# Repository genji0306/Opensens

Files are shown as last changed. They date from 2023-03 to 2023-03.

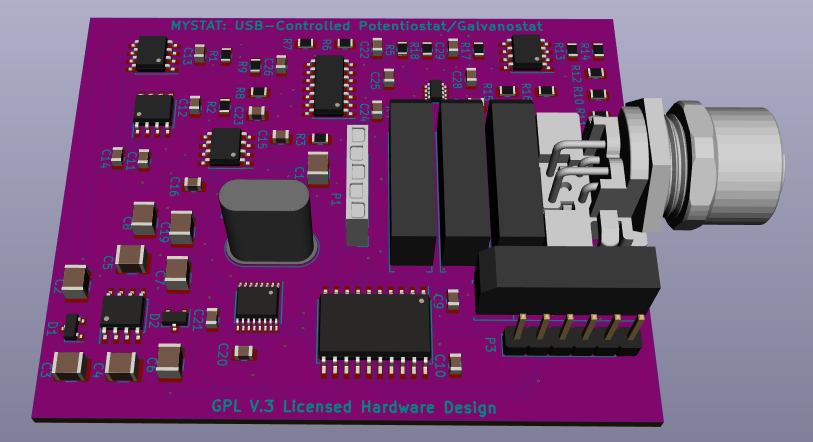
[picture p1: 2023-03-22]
OEPS V2b Zenodo Based/pcb_3dview.png

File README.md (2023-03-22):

# Opensens
Opensource Potentiostat
Sau khi chia sẻ điện cực in SPE, Lab em đã nhận được sự nhiều sự quan tâm và liên hệ. Nhóm em nhận thấy là hiện tại việc nghiên cứu về Electrochemistry và Biosensor của các nhóm nghiên cứ ở trong VN còn nhiều khó khăn đặt biệt là về vấn đề thiết bị. Chính vì vậy, lab em quyết định chia sẻ phần nghiên cứu về thiết bị đo điện hoá Potentiostat/Galvanostat cho mọi người, hy vọng có thể giảm bớt khó khăn khi nghiên cứu trong nước Potentiostat/Galvanostat do nhóm DYNLAB- PGS. Thuỷ, thuộc Bộ Môn Điện Hoá, Đại Học Bách Khoa Hà Nội và nhóm PGS. Nguyên, ĐH KHTN HCM - phát triển – tên mã project là OEPS – tên chính thức là Opensens, được phát triển từ cuối năm 2017 với mục tiêu là tạo ra thiết bị đo điện hoá nhỏ gọn tin cậy độ phân giải cao, giá thành hợp lý để triển khai giám sát trên diện rộng. Version đầu tiên dựa trên phiên bản của TS. Dobbelaere và bản sau này của Irving (NCS của Dobbelaere). Phiên bản OEPS V1 dựa trên hardware với một số thay đổi về linh kiện, firmware và phần mềm. Sau 5 năm nghiên cứu, hiện nhóm đã phát triển nhiều Version khác nhau phục vụ cho nghiên cứu về Nguồn điện (Pin), Cảm Biến và giám sát môi trường. 
Trong link chia sẻ là bản OEPS V1/V2, MFO V1 và cả Software gốc/ Software của lab: 
- OEPS V1: Gồm một số tính năng: LSV, CV, CP, CA, Phóng nạp Pin - dải điện áp +-8V 30mA - hiệu chỉnh lỗi và tương thích software bản mới. (DAC 22 bits - độ phân giải 4pA) 
- OEPS V2: Dải điện áp +-12V 250mA - modify chống nhiễu, thay đổi linh kiện giá hợp lý hơn và chỉnh sửa lại Software.
- MFO V1: Phiên bản rút gọn đo 1 phép đo set up sẵn dùng cho y sinh/ môi trường. Có khả năng đo được hầu hết các phép đo LSV,CV,CP,CA, DPV, NPV, EIS(<34khz) (độ phân giải thấp – 12 bits) 
Các phiên bản trên đã được chạy thử nghiệm ít nhất 2 năm và nhiều nhất là từ khi dự án được tiến hành, đã so sánh với thiết bị thương mại như Autolab, Biologic và Palmsens. Các phiên bản khác của lab được tích hơn thêm Pulse technique và EIS sẽ sớm được opensource trong thời gian tiếp theo. Nếu muốn trải nghiệm thiết bị, xin mời mọi người qua DHBK HN ở Hà Nội gặp và Trường DH KHTN HCM ở HCM gặp PGS. Nguyên .

Chi phí linh kiện của thiết bị dao động từ $120-150, tuy nhiên thực tế tuỳ số lượng, đơn vị gia công và thuế nhập khẩu, chi phí sx rơi vào tầm 5-8tr/ thiết bị. Mọi người chỉ cần gửi link và liên hệ bên điện điện tử là được. Cũng chia sẻ luôn, tầm giữa tháng 4 tại bên lab sẽ đặt thêm linh kiện và gia công thiết bị (phiên bản mới) nhưng có chung nhiều linh kiện phiên bản cũ. Vì vậy nếu cần thì bên em có thể đặt giúp mọi người. Chi tiết xin liên hệ sdt: 033. 616.4867 

Ps: do phải tách repo Git để opensource nên dữ liệu sẽ được upload dần từ giờ tới cuối tuần

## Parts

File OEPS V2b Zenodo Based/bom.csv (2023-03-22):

Component | Description | Part | References | Value | Footprint | Quantity Per PCB | Datasheet | Part Number | Manufacturer
1 | Unpolarized capacitor | C_Small | C9 C10 C11 C12 C13 C14 C15 C16 C22 C23 C25 C27 C28 | 0.1 µF | C_0805_2012Metric | 13 | https://api.kemet.com/component-edge/download/datasheet/C0805C104J5RALTU.pdf | C0805C104J5RAL7800 C0805C104J3RACTU | KEMET
2 | Unpolarized capacitor | C_Small | C21 | 10 nF | C_0805_2012Metric | 1 | https://api.kemet.com/component-edge/download/datasheet/C0805C103J5GACTU.pdf | C0805C103J5GACTU | KEMET
3 | Unpolarized capacitor | C_Small | C1 C2 C3 C4 C5 C6 C7 C8 C19 | 10 µF | C_1210_3225Metric | 9 | http://search.murata.co.jp/Ceramy/image/img/A01X/G101/ENG/GRM32DR71E106KA12-01.pdf | GRM32DR71E106KA12L | Murata Electronics North America
4 | Unpolarized capacitor | C_Small | C17 C18 C26 C29 | 12 pF | C_0805_2012Metric | 4 | http://www.yageo.com/documents/recent/UPY-GP_NP0_16V-to-50V_16.pdf | CC0805FRNPO9BN120 | Yageo
5 | Unpolarized capacitor | C_Small | C20 | 3.3 nF | C_0805_2012Metric | 1 | https://www.murata.com/~/media/webrenewal/support/library/catalog/products/capacitor/mlcc/c02e.ashx | GRM2165C1H332FA01J | Murata Electronics North America
6 | Unpolarized capacitor | C_Small | C24 | 4700 pF | C_0805_2012Metric | 1 | https://api.kemet.com/component-edge/download/datasheet/C0805C472K5RACTU.pdf | C0805C472K5RACTU | KEMET
7 | Dual schottky diode | D_Schottky_x2_Serial_AKC | D1 D2 | BAT721S | SOT-23 | 2 | https://assets.nexperia.com/documents/data-sheet/1PS76SB21_BAT721_SER.pdf | BAT721S,215 | Nexperia USA Inc.
8 |  | 9007-05-01 | K1 K2 K3 K4 | 9007-05-01 | RELAY-9007 | 4 | https://cotorelay.com/wp-content/uploads/2014/09/9007_series_reed_relay_datasheet.pdf | 9007-05-01 | Coto Technology
9 | Generic connector, single row, 01x05, script generated (kicad-library-utils/schlib/autogen/connector/) | Conn_01x05 | P2 | CELL | T4145035041-001 | 1 | http://www.te.com/commerce/DocumentDelivery/DDEController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 | T4145035041-001 | TE Connectivity AMP Connectors
10 | Generic connector, single row, 01x06, script generated (kicad-library-utils/schlib/autogen/connector/) | Conn_01x06 | P3 | ICSP | PinHeader_1x06_P2.54mm_Vertical | 1 | https://media.digikey.com/PDF/Data%20Sheets/Sullins%20PDFs/xRxCzzzSxxN-RC_ST_11635-B.pdf | PRPC006SAAN-RC | Sullins Connector Solutions
11 |  | USB_Header | P1 | USB Terminal | PinHeader_1x05_P2.54mm_Vertical | 1 | http://www.te.com/commerce/DocumentDelivery/DDEController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 | 215297-5 | TE Connectivity AMP Connectors
12 | Resistor, small symbol | R_Small | R12 | 100k* | R_0805_2012Metric | 1 | https://industrial.panasonic.com/cdbs/www-data/pdf/RDM0000/AOA0000C307.pdf | ERA-6AEB104V | Panasonic Electronic Components
13 | Resistor, small symbol | R_Small | R10 | 10R* | R_0805_2012Metric | 1 | http://www.te.com/commerce/DocumentDelivery/DDEController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 | CPF0805B10RE | TE Connectivity Passive Product
14 | Resistor, small symbol | R_Small | R2 R5 | 10k | R_0805_2012Metric | 2 | http://www.yageo.com/documents/recent/PYu-RC_Group_51_RoHS_L_9.pdf | RC0805FR-0710KL | Yageo
15 | Resistor, small symbol | R_Small | R13 | 18k* | R_0805_2012Metric | 1 | https://industrial.panasonic.com/cdbs/www-data/pdf/RDM0000/AOA0000C307.pdf | ERA-6AEB183V | Panasonic Electronic Components
16 | Resistor, small symbol | R_Small | R1 R3 | 1k | R_0805_2012Metric | 2 | http://www.yageo.com/documents/recent/PYu-RC_Group_51_RoHS_L_9.pdf | RC0805FR-071KL | Yageo
17 | Resistor, small symbol | R_Small | R11 | 1k* | R_0805_2012Metric | 1 | https://industrial.panasonic.com/cdbs/www-data/pdf/RDM0000/AOA0000C307.pdf | ERA-6AEB102V | Panasonic Electronic Components
18 | Resistor, small symbol | R_Small | R6 R8 | 240k* | R_0805_2012Metric | 2 | http://www.susumu.co.jp/common/pdf/n_catalog_partition01_en.pdf | RG2012N-244-W-T1 | Susumu
19 | Resistor, small symbol | R_Small | R4 | 27R | R_0805_2012Metric | 1 | http://www.yageo.com/documents/recent/PYu-RC_Group_51_RoHS_L_9.pdf | RC0805FR-0727RL | Yageo
20 | Resistor, small symbol | R_Small | R14 | 2k* | R_0805_2012Metric | 1 | https://industrial.panasonic.com/cdbs/www-data/pdf/RDM0000/AOA0000C307.pdf | ERA-6AEB202V | Panasonic Electronic Components
21 | Resistor, small symbol | R_Small | R7 R9 R15 R16 R17 R18 | 75k* | R_0805_2012Metric | 6 | https://industrial.panasonic.com/cdbs/www-data/pdf/RDM0000/AOA0000C307.pdf | ERA-6ARW753V | Panasonic Electronic Components
22 |  | ADR421 | U3 | ADR421 | SOIC-8_3.9x4.9mm_P1.27mm | 1 | http://www.analog.com/media/en/technical-documentation/data-sheets/ADR420_421_423_425.pdf | ADR421ARZ | Analog Devices Inc.
23 |  | DAC1220 | U6 | DAC1220 | SSOP-16_3.9x4.9mm_P0.635mm | 1 | http://www.ti.com/lit/ds/symlink/dac1220.pdf | DAC1220E | Texas Instruments
24 |  | DG449 | U8 | DG449 | sot23-8 | 1 | http://www.vishay.com/docs/73897/dg449.pdf | DG449DS-T1-E3 | Vishay Siliconix
25 |  | LM2662 | U1 | LM2662 | SOIC-8_3.9x4.9mm_P1.27mm | 1 | http://www.ti.com/lit/ds/symlink/lm2662.pdf | LM2662M/NOPB | Texas Instruments
26 |  | MCP3550 | U4 U5 | MCP3553 | SOIC-8_3.9x4.9mm_P1.27mm | 2 | http://www.microchip.com/mymicrochip/filehandler.aspx?ddocname=en024716 | MCP3553-E/SN | Microchip Technology
27 |  | OPA2192 | U9 | OPA2192 | SOIC-8_3.9x4.9mm_P1.27mm | 1 | http://www.ti.com/lit/ds/symlink/opa192.pdf | OPA2192IDR | Texas Instruments
28 |  | OPA4192 | U7 | OPA4192 | SOIC-14_3.9x8.7mm_P1.27mm | 1 | http://www.ti.com/lit/ds/symlink/opa4192.pdf | OPA4192IDR | Texas Instruments
29 |  | PIC16F1459 | U2 | PIC16F1459 | SOIC-20W_7.5x12.8mm_P1.27mm | 1 | http://www.microchip.com/mymicrochip/filehandler.aspx?ddocname=en558409 | PIC16F1459-I/SO | Microchip Technology
30 | Two pin crystal, small symbol | Crystal_Small | X1 | 2.5 MHz | Crystal_HC49-U_Vertical | 1 | http://www.ecsxtal.com/store/pdf/hc49ux.pdf | ECS-25-S-1X | ECS Inc.
Component Groups: | 30
Component Count: | 66
Fitted Components: | 66
Number of PCBs: | 1
Total components: | 66
Schematic Version: | 1
Schematic Date: | 2018-07-27
BoM Date: | Fri 27 Jul 2018 05:08:33 PM EDT
Schematic Source: | /home/matt/mystat-master/kicad3/mystat.sch
KiCad Version: | Eeschema 5.0.0+dfsg1-1

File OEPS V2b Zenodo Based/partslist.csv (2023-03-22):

Index | Quantity | Part Number | Description | Customer Reference | Available Quantity | Backorder Quantity | Unit Price USD | Extended Price USD
1 | 1 | 399-7992-1-ND | CAP CER 10000PF 50V C0G/NP0 0805 |  | 1 | 0 | 0.69 | 0.69
2 | 4 | 311-4162-1-ND | CAP CER 12PF 50V NPO 0805 |  | 4 | 0 | 0.3 | 1.2
3 | 1 | 490-8287-1-ND | CAP CER 3300PF 50V C0G/NP0 0805 |  | 1 | 0 | 0.49 | 0.49
4 | 1 | 399-1155-1-ND | CAP CER 4700PF 50V X7R 0805 |  | 1 | 0 | 0.1 | 0.1
5 | 2 | 1727-3574-1-ND | DIODE ARRAY SCHOTTKY 40V SOT23 |  | 2 | 0 | 0.45 | 0.9
6 | 4 | 306-1063-ND | RELAY REED SPST 500MA 5V |  | 4 | 0 | 1.43 | 5.72
7 | 1 | A126527-ND | CONN RCPT FMALE 4POS GOLD SOLDER |  | 1 | 0 | 10.44 | 10.44
8 | 1 | S1011EC-06-ND | CONN HEADER .100" SNGL STR 6POS |  | 1 | 0 | 0.23 | 0.23
9 | 1 | A113138-ND | CONN RCPT HV-100 SRS VERT 5POS |  | 1 | 0 | 1.1 | 1.1
10 | 1 | P100KDACT-ND | RES SMD 100K OHM 0.1% 1/8W 0805 |  | 1 | 0 | 0.41 | 0.41
11 | 1 | A119971CT-ND | RES SMD 10 OHM 0.1% 1/10W 0805 |  | 1 | 0 | 0.53 | 0.53
12 | 2 | 311-10.0KCRCT-ND | RES SMD 10K OHM 1% 1/8W 0805 |  | 2 | 0 | 0.1 | 0.2
13 | 1 | P18KDACT-ND | RES SMD 18K OHM 0.1% 1/8W 0805 |  | 1 | 0 | 0.41 | 0.41
14 | 2 | 311-1.00KCRCT-ND | RES SMD 1K OHM 1% 1/8W 0805 |  | 2 | 0 | 0.1 | 0.2
15 | 1 | P1.0KDACT-ND | RES SMD 1K OHM 0.1% 1/8W 0805 |  | 1 | 0 | 0.41 | 0.41
16 | 2 | RG20N240KWCT-ND | RES SMD 240K OHM 0.05% 1/8W 0805 |  | 2 | 0 | 0.93 | 1.86
17 | 1 | 311-27.0CRCT-ND | RES SMD 27 OHM 1% 1/8W 0805 |  | 1 | 0 | 0.1 | 0.1
18 | 1 | P2.0KDACT-ND | RES SMD 2K OHM 0.1% 1/8W 0805 |  | 1 | 0 | 0.41 | 0.41
19 | 6 | P75KBSCT-ND | RES SMD 75K OHM 0.05% 1/8W 0805 |  | 6 | 0 | 0.82 | 4.92
20 | 1 | ADR421ARZ-ND | IC VREF SERIES 2.5V 8SOIC |  | 1 | 0 | 6.62 | 6.62
21 | 1 | DAC1220E-ND | IC 20-BIT MONOLITHIC D/A 16SSOP |  | 1 | 0 | 19.8 | 19.8
22 | 1 | DG449DS-T1-E3CT-ND | IC SWITCH SINGLE SPDT SOT23-8 |  | 1 | 0 | 1.5 | 1.5
23 | 1 | LM2662M/NOPB-ND | IC REG SWTCHD CAP INV 0.2A 8SOIC |  | 1 | 0 | 2.57 | 2.57
24 | 2 | MCP3553-E/SN-ND | IC ADC 22BIT 2.7V 1CH SPI 8SOIC |  | 2 | 0 | 4.1 | 8.2
25 | 1 | 296-42106-1-ND | IC OP AMP RRIO E-TRIM 8SOIC |  | 1 | 0 | 4.2 | 4.2
26 | 1 | 296-43159-1-ND | IC OPAMP RRI/O 14SOIC |  | 1 | 0 | 6.61 | 6.61
27 | 1 | PIC16F1459-I/SO-ND | IC MCU 8BIT 14KB FLASH 20SOIC |  | 1 | 0 | 1.82 | 1.82
28 | 1 | X1003-ND | CRYSTAL 2.5000MHZ SERIES T/H |  | 1 | 0 | 1.13 | 1.13
29 | 9 | 490-1867-1-ND | CAP CER 10UF 25V X7R 1210 |  | 9 | 0 | 0.83 | 7.47
30 | 1 | HM3149-ND | BOX ALUM BLACK 3.48"L X 2.44"W |  | 1 | 0 | 26.95 | 26.95
31 | 1 | 708-1230-ND | CABLE IP68 MINI B TO A USB 3M |  | 1 | 0 | 19.77 | 19.77
32 | 1 | 708-1236-ND | CABLE IP68 B MINI USB-5WAY HEADE |  | 1 | 0 | 10.58 | 10.58
33 | 1 | 277-12857-ND | SENSOR/ACTUATOR CABLE 4POS |  | 1 | 0 | 14.96 | 14.96

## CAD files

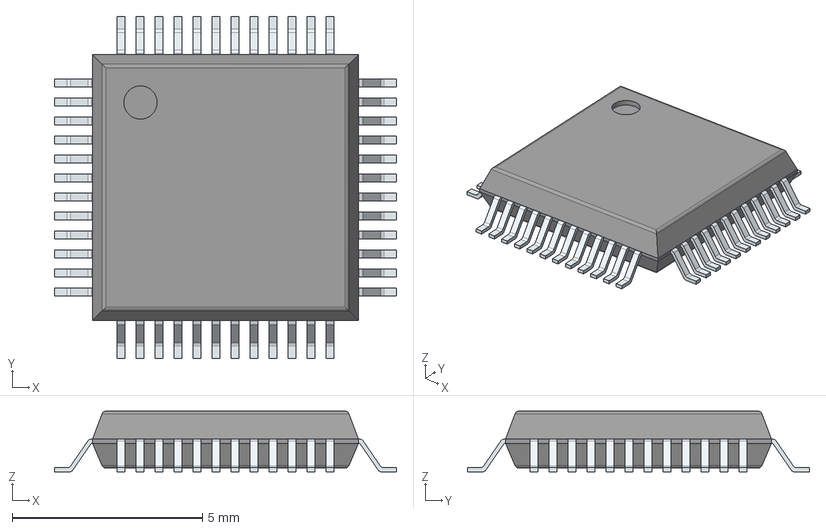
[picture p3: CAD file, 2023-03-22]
OEPS V2 STM/STM32F072C8T6-pcb-part-libraries/STM32F072C8T6.stp
9.00 x 9.00 x 1.60 mm
PinsArrayLR
PinsArrayTB

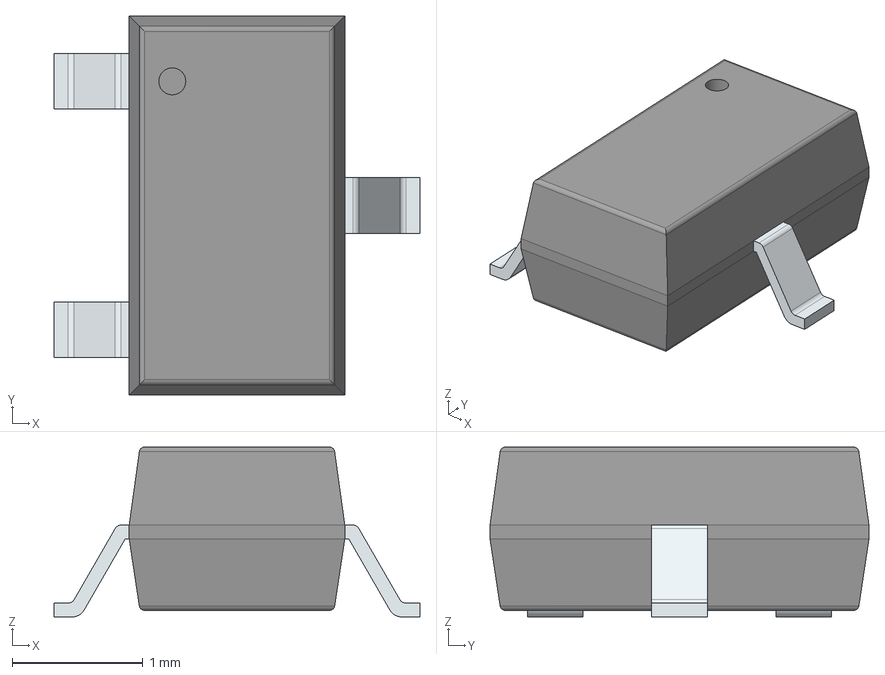
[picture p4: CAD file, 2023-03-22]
OEPS V2 STM/XC6206P332MR-G-pcb-part-libraries/XC6206P332MR-G.stp
2.80 x 2.90 x 1.30 mm
PinsArrayL
FilletPinR

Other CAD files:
OEPS V2 STM/STM32F072C8T6-pcb-part-libraries/STM32F072C8T6.stl
OEPS V2 STM/XC6206P332MR-G-pcb-part-libraries/XC6206P332MR-G.stl

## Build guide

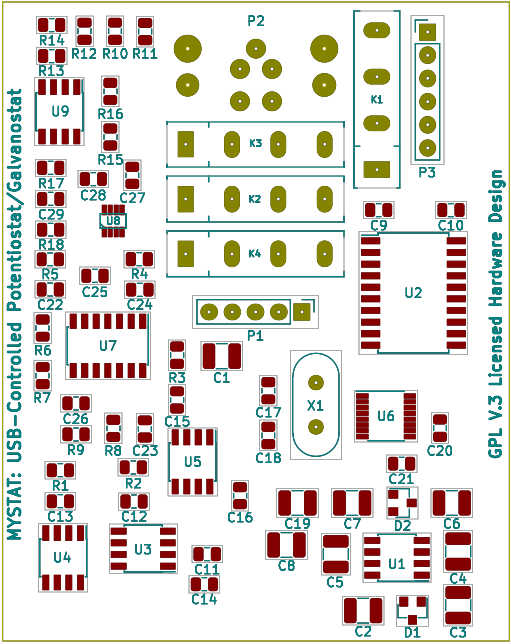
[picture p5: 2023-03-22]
OEPS V2b Zenodo Based/pcb_fabrication_diagram.png

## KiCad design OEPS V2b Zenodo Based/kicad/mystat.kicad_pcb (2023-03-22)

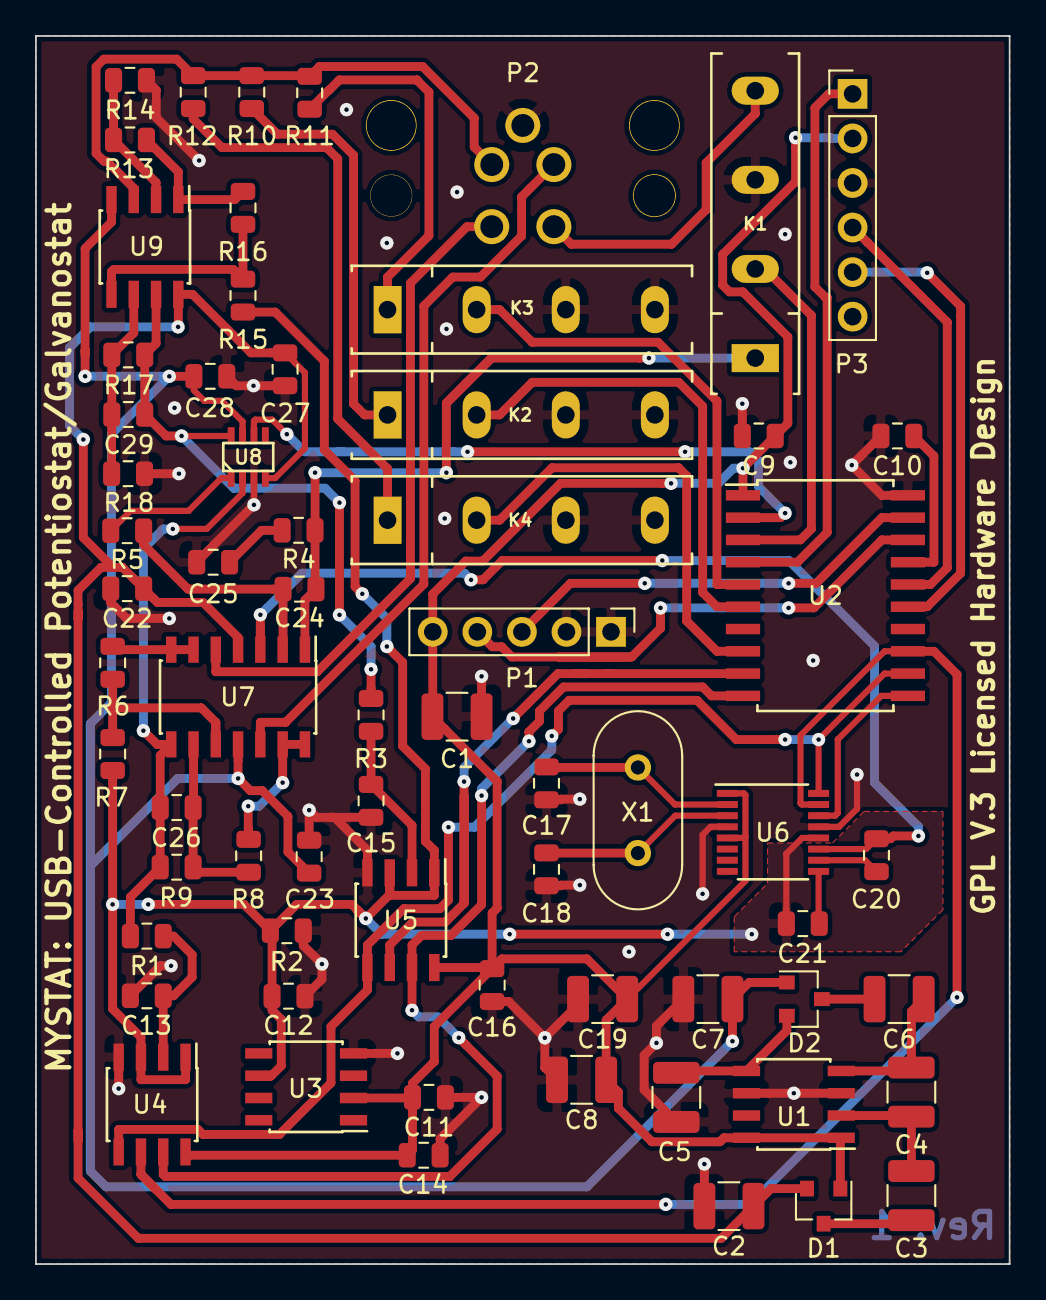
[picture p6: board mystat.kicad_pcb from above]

Board: 2 copper layers, 55.5 x 70.0 mm, 66 parts (0 on the bottom side), 54 nets.

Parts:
C1, C2, C3, C4, C5, C6, C7, C8, C19: 10 µF; C_1210_3225Metric
C9, C10, C11, C12, C13, C14, C15, C16, C22, C23, C25, C27, C28: 0.1 µF; C_0805_2012Metric
C17, C18, C26, C29: 12 pF; C_0805_2012Metric
C20: 3.3 nF; C_0805_2012Metric
C21: 10 nF; C_0805_2012Metric
C24: 4700 pF; C_0805_2012Metric
D1, D2: BAT721S; SOT-23
K1, K2, K3, K4: 9007-05-01; RELAY-9007
P1: USB Terminal; PinHeader_1x05_P2.54mm_Vertical
P2: CELL; T4145035041-001
P3: ICSP; PinHeader_1x06_P2.54mm_Vertical
R1, R3: 1k; R_0805_2012Metric
R2, R5: 10k; R_0805_2012Metric
R4: 27R; R_0805_2012Metric
R6, R8: 240k*; R_0805_2012Metric
R7, R9, R15, R16, R17, R18: 75k*; R_0805_2012Metric
R10: 10R*; R_0805_2012Metric
R11: 1k*; R_0805_2012Metric
R12: 100k*; R_0805_2012Metric
R13: 18k*; R_0805_2012Metric
R14: 2k*; R_0805_2012Metric
U1: LM2662; SOIC-8_3.9x4.9mm_P1.27mm
U2: PIC16F1459; SOIC-20W_7.5x12.8mm_P1.27mm
U3: ADR421; SOIC-8_3.9x4.9mm_P1.27mm
U4, U5: MCP3553; SOIC-8_3.9x4.9mm_P1.27mm
U6: DAC1220; SSOP-16_3.9x4.9mm_P0.635mm
U7: OPA4192; SOIC-14_3.9x8.7mm_P1.27mm
U8: DG449; sot23-8
U9: OPA2192; SOIC-8_3.9x4.9mm_P1.27mm
X1: 2.5 MHz; Crystal_HC49-U_Vertical

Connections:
+5V: C1.1, C8.1, C9.1, C11.1, C14.1, C16.1, C19.1, D1.1, P1.1, P3.2, U1.1, U1.8, U2.1, U3.2, U4.8, U5.8, U6.1, U6.5
+9V: C2.1, C22.2, C27.2, D1.2, U7.4, U8.4, U9.8
-9V: C7.2, C23.1, C28.1, D2.1, U7.11, U8.7, U9.4
/CE: P2.3, R10.1, R11.1, R12.1, U9.3
/CELL_ON: K1.2, U2.3
/CS1: U2.11, U6.14
/CS2: U2.10, U4.7, U5.7
/ICSPCLK: P3.5, U2.15
/ICSPDAT: P3.4, U2.16
/I_MEAS: C29.2, R3.1, R17.2, U8.8, U9.7
/MCLR: P3.1, U2.4
/MODE_SW: U2.2, U8.6
/RANGE1: K2.2, U2.6
/RANGE2: K3.2, U2.5
/RANGE3: K4.2, U2.8
/RE: P2.4, U7.12
/SCK: U2.12, U4.5, U5.5, U6.16
/SDIO: U2.13, U4.6, U6.15
/SDIO2: U2.9, U5.6
/SE: P2.2, U7.5
/USB_D+: P1.3, U2.19
/USB_D-: P1.2, U2.18
/VREF: C12.1, C21.2, R2.1, R7.2, R15.1, U3.6, U4.1, U4.3, U5.1, U5.3, U6.12
/V_MEAS: C26.2, R1.1, R9.1, U7.8, U8.2
/WE: K1.4, P2.1
GND: C1.2, C2.2, C5.1, C7.1, C8.2, C9.2, C10.2, C11.2, C12.2, C13.2, C14.2, C15.2, C16.2, C17.2, C18.2, C19.2, C22.1, C23.2, C25.2, C27.1, C28.2, K1.3, K2.3, K2.4, K3.3, K3.4, K4.3, K4.4, P1.4, P1.5, P2.5, P3.3, R2.2, R14.2, R18.2, U1.3, U1.6, U2.20, U3.4, U4.4, U5.4, U6.4, U6.13, U8.3
unnamed: C3.1, D1.3
unnamed: C3.2, C4.1, U1.2
unnamed: C4.2, C6.1, U1.4
unnamed: C5.2, D2.2, U1.5
unnamed: C6.2, D2.3
unnamed: C10.1, U2.17
unnamed: C13.1, R1.2, U4.2
unnamed: C15.1, R3.2, U5.2
unnamed: C17.1, U6.2, X1.1
unnamed: C18.1, U6.3, X1.2
unnamed: C20.1, U6.10
unnamed: C20.2, U6.11, U7.3
unnamed: C21.1, U6.9
unnamed: C24.1, K1.1, R4.1, U7.1
unnamed: C24.2, R5.1, U7.2
unnamed: C25.1, R4.2
unnamed: C26.1, R8.1, R9.2, U7.9
unnamed: C29.1, R17.1, R18.1, U9.6
unnamed: K2.1, R10.2
unnamed: K3.1, R11.2
unnamed: K4.1, R12.2
unnamed: R5.2, U8.1
unnamed: R6.1, U7.6, U7.7
unnamed: R6.2, R7.1, U7.10
unnamed: R8.2, U7.13, U7.14
unnamed: R13.1, R14.1, U9.2
unnamed: R13.2, R16.1, U9.1
unnamed: R15.2, R16.2, U9.5

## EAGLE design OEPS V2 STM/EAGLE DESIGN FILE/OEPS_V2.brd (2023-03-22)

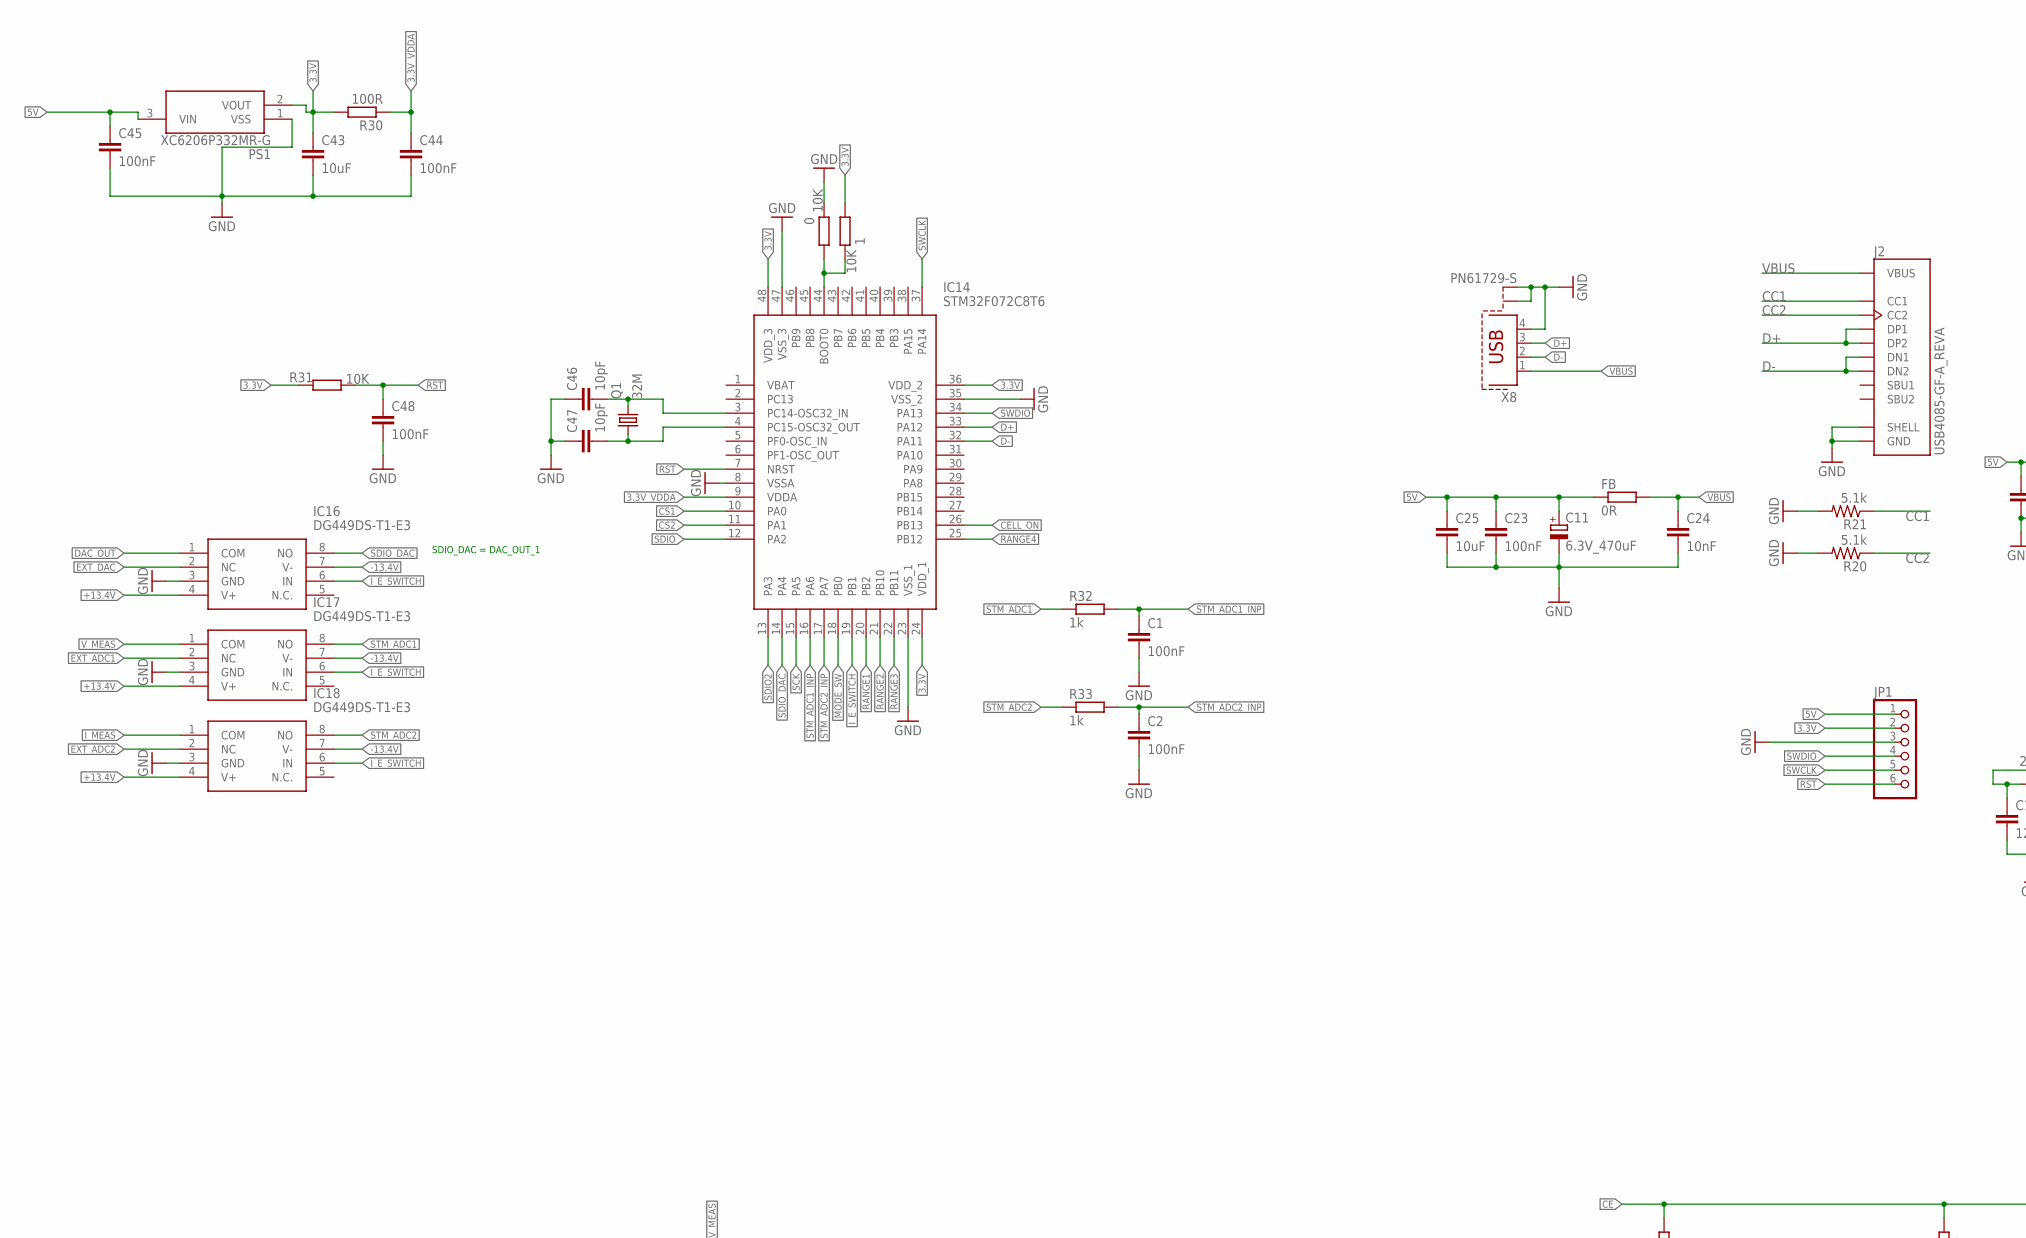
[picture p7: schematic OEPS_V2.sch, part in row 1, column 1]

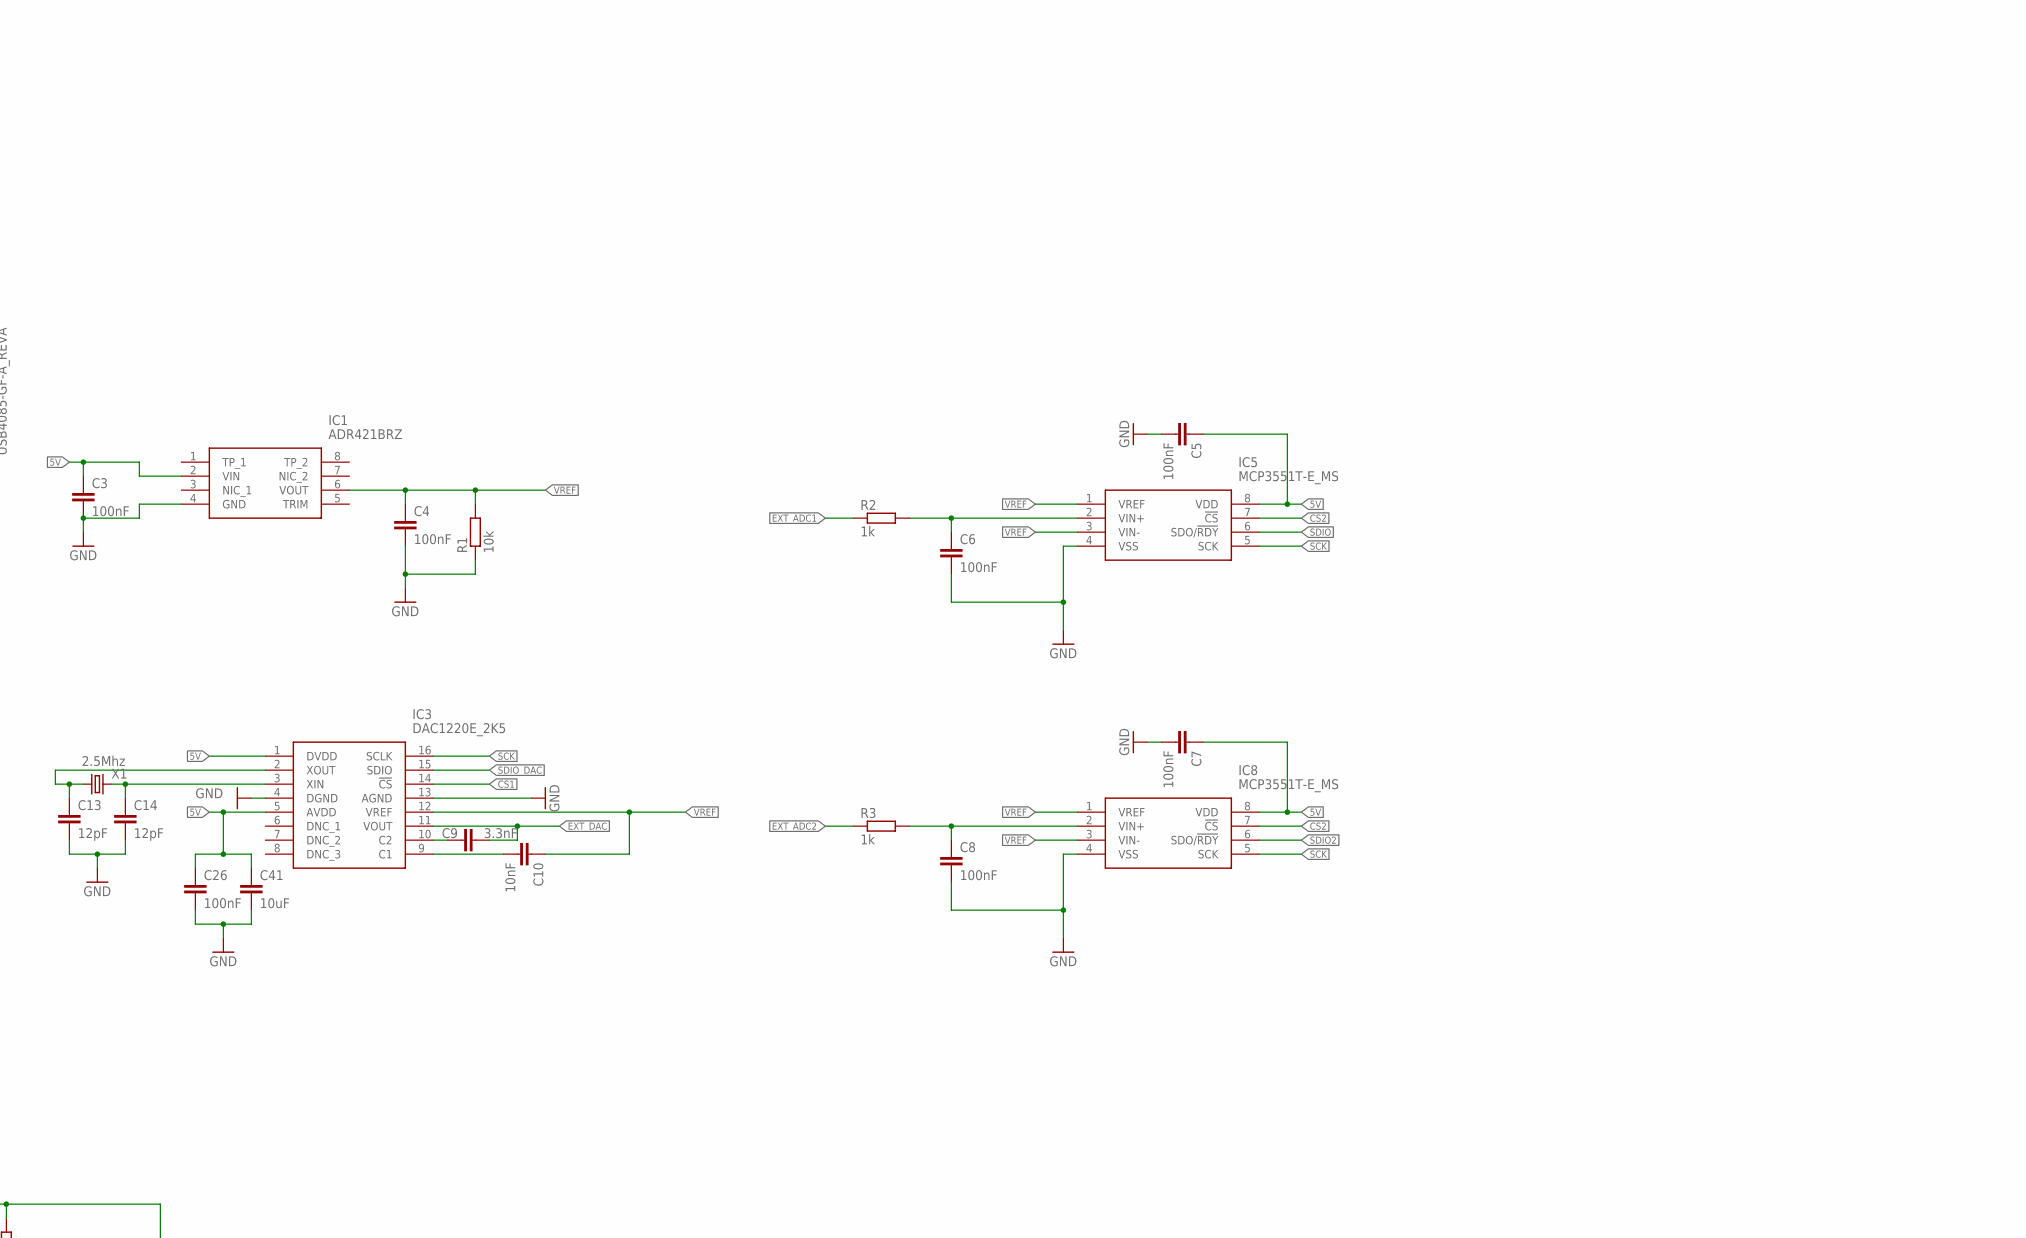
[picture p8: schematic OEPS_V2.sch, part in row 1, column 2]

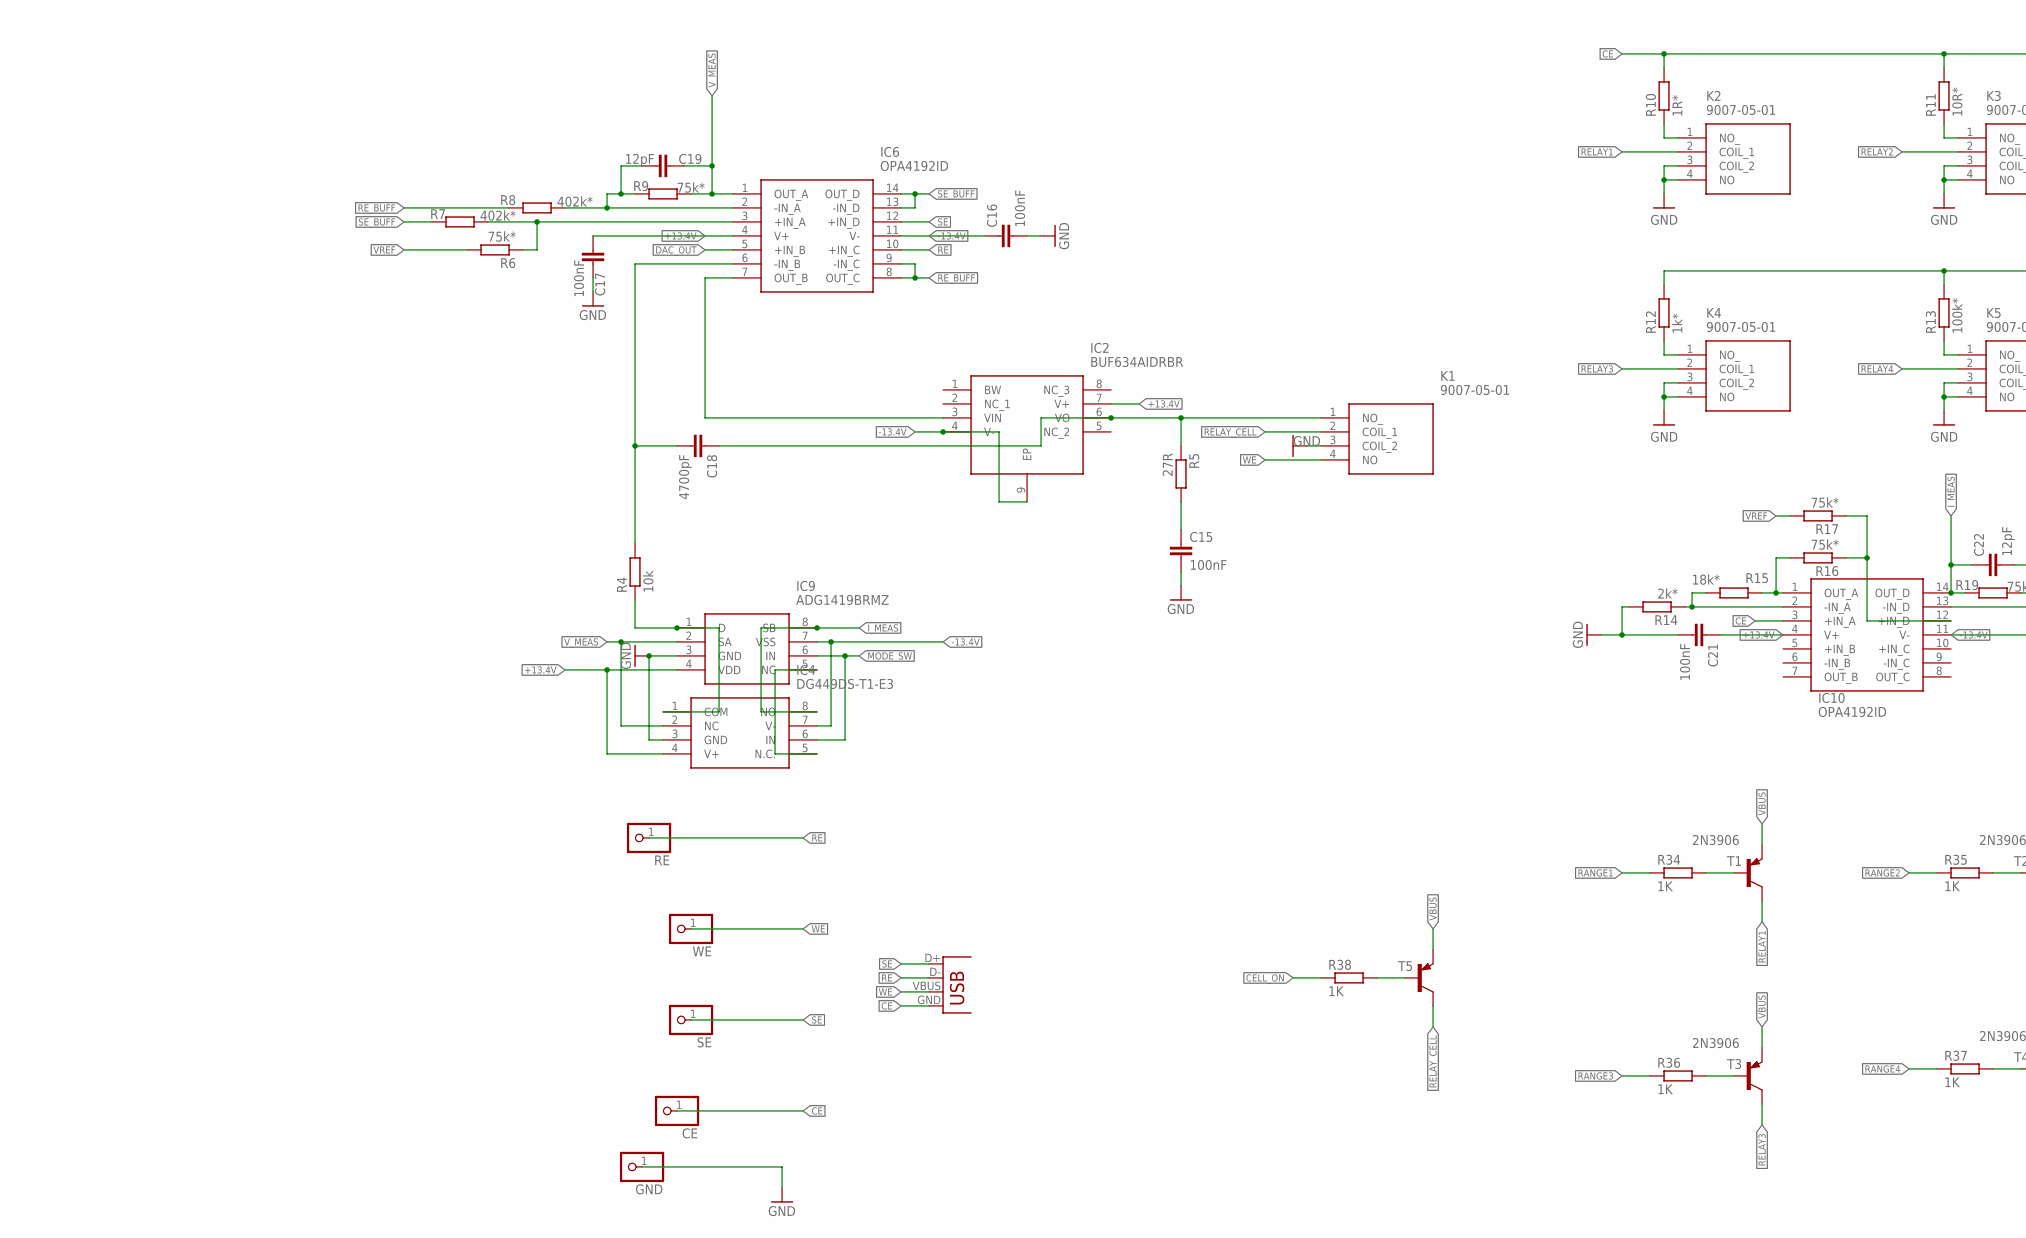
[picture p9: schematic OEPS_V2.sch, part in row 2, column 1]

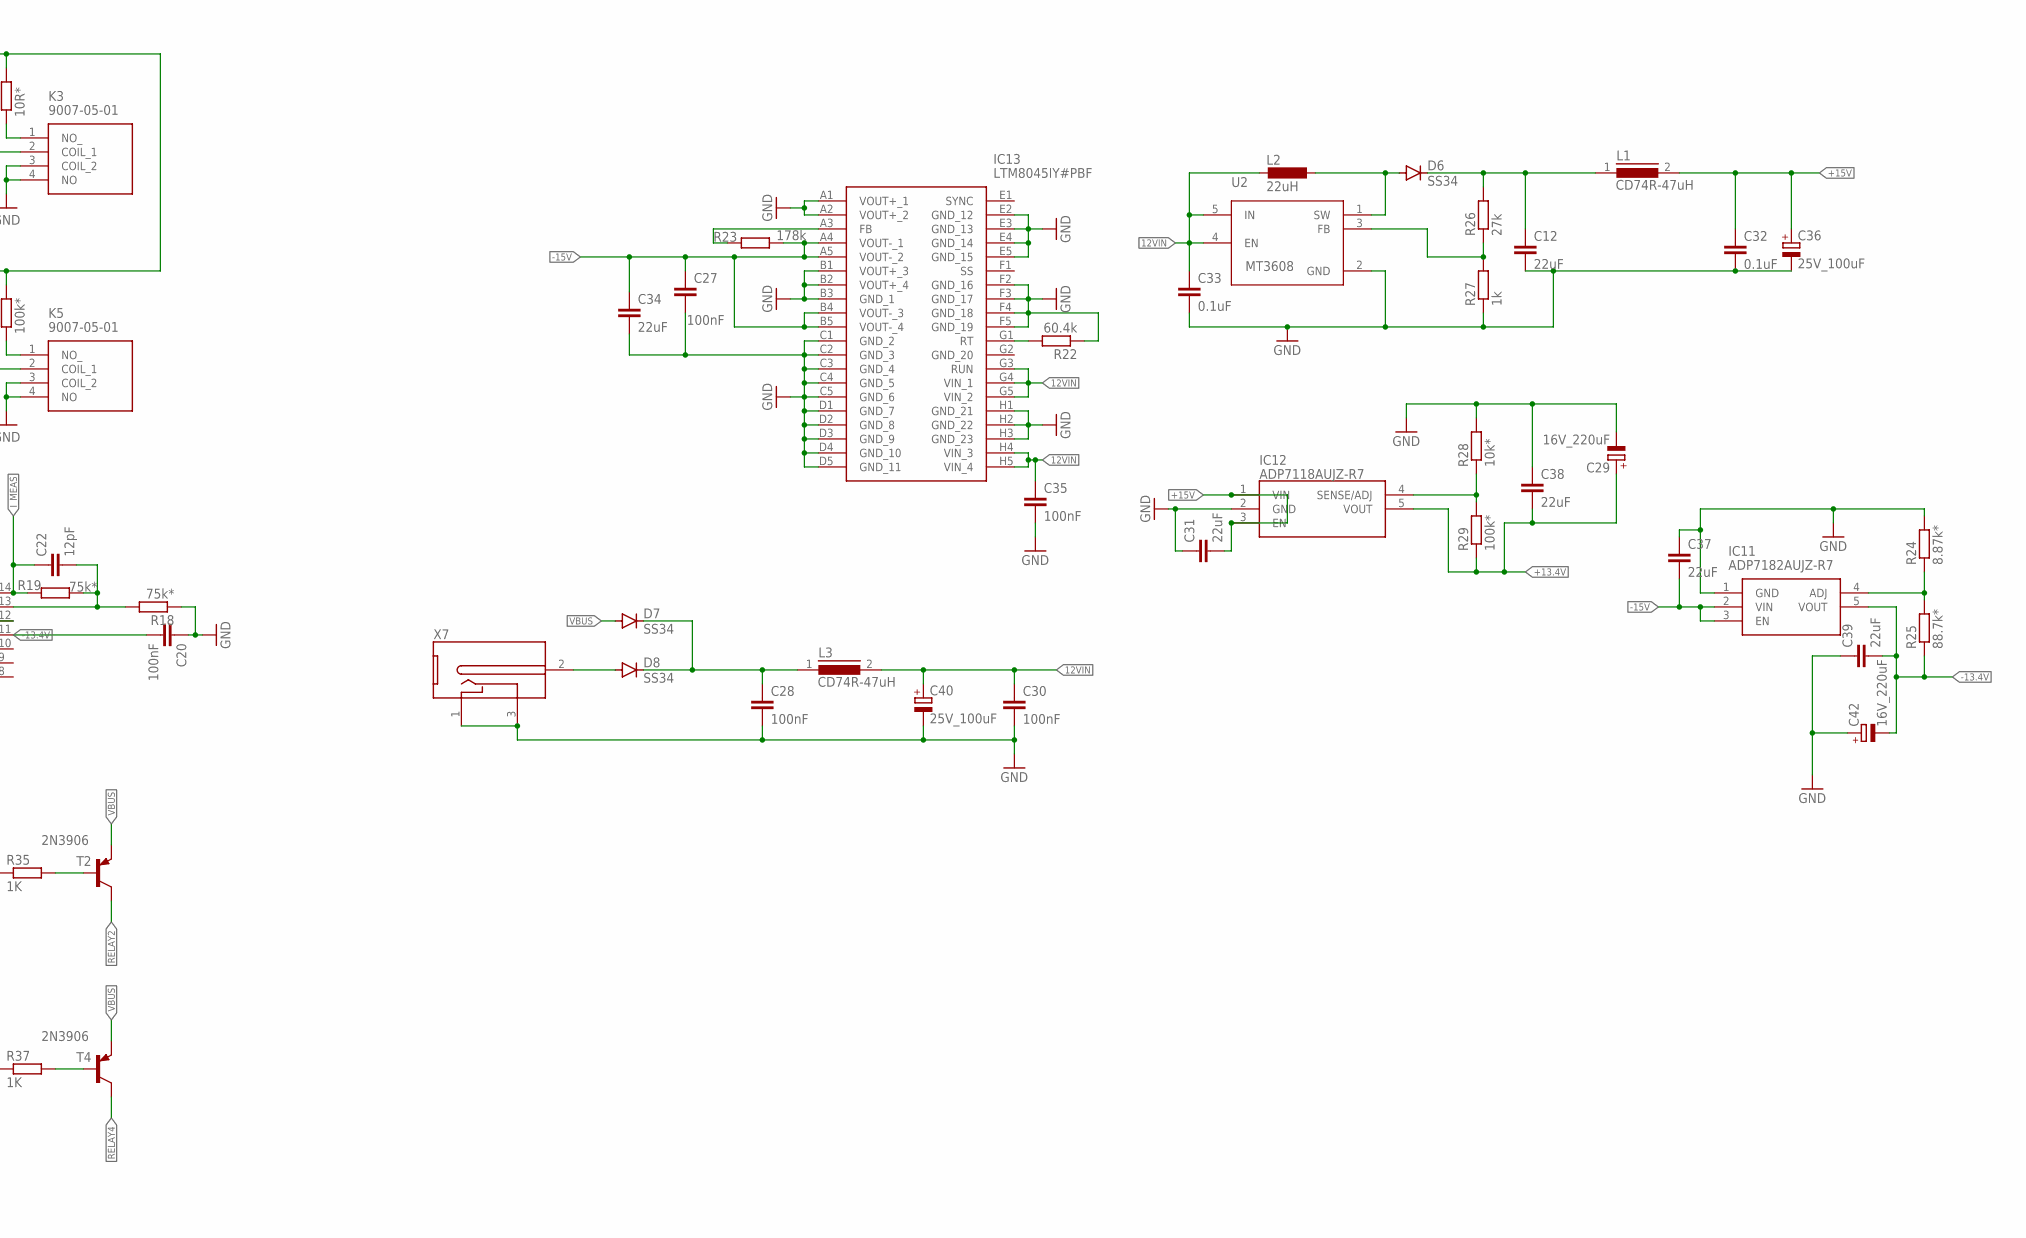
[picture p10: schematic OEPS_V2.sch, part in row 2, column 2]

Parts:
0, 1: 10K; R0603
C1, C2, C3, C4, C5, C6, C7, C8, C15, C16, C17, C20, C21, C23, C26, C44, C45, C48: 100nF; C0603
C9: 3.3nF; C0603
C10, C24: 10nF; C0603
C11: 6.3V_470uF; 153CLV-0605
C12, C31, C34, C37, C38, C39: 22uF; C1206
C13, C14, C19, C22: 12pF; C0603
C18: 4700pF; C0603
C25, C41, C43: 10uF; C0603
C27, C28, C30, C35: 100nF; C0805
C29, C42: 16V_220uF; 153CLV-0605
C32, C33: 0.1uF; C0805
C36, C40: 25V_100uF; 153CLV-0605
C46, C47: 10pF; C0603
CE: PINHD-1X1; 1X01
D6, D7, D8: SS34; DO-214AC
FB: 0R; R0805
GND: PINHD-1X1; 1X01
IC1: ADR421BRZ; SOIC127P600X175-8N
IC2: BUF634AIDRBR; SON65P300X300X100-9N
IC3: DAC1220E_2K5; SOP64P600X175-16N
IC4, IC16, IC17, IC18: DG449DS-T1-E3; SOP65P280X145-8N
IC5, IC8: MCP3551T-E_MS; SOP65P490X110-8N@1
IC6, IC10: OPA4192ID; SOIC127P600X175-14N
IC9: ADG1419BRMZ; SOP65P490X110-8N
IC11: ADP7182AUJZ-R7; SOT95P280X100-5N
IC12: ADP7118AUJZ-R7; SOT95P280X100-5N
IC13: LTM8045IY#PBF; BGA40C127P5X8_625X1125X512
IC14: STM32F072C8T6; QFP50P900X900X160-48N
J2: USB4085-GF-A_REVA; GCT_USB4085-GF-A_REVA
JP1: PINHD-1X6; 1X06
K1, K2, K3, K4, K5: 9007-05-01; 90070501
L1, L3: CD74R-47uH; DR74
L2: 22uH; PIS2816
PS1: XC6206P332MR-G; SOT95P280X130-3N
Q1: 32M; 3.2X2.5_KX-7
R1, R4: 10k; R0603
R2, R3, R27, R32, R33: 1k; R0603
R5: 27R; R0603
R6, R9, R16, R17, R18, R19: 75k*; R0603
R7, R8: 402k*; R0603
R10: 1R*; R0805
R11: 10R*; R0805
R12: 1k*; R0805
R13: 100k*; R0805
R14: 2k*; R0603
R15: 18k*; R0603
R20, R21: 5.1k; R0603
R22: 60.4k; R0603
R23: 178k; R0603
R24: 8.87k*; R0603
R25: 88.7k*; R0603
R26: 27k; R0603
R28: 10k*; R0603
R29: 100k*; R0603
R30: 100R; R0603
R31: 10K; R0603
R34, R35, R36, R37, R38: 1K; R0603
RE: PINHD-1X1; 1X01
SE: PINHD-1X1; 1X01
T1, T2, T3, T4: 2N3906; SOT23-BEC
T5: MMBT3906LT1-PNP-SOT23-BEC; SOT23-BEC
U2: MT3608; SOT95P280X145-6N
WE: PINHD-1X1; 1X01
X1: 2.5Mhz; HC49
X6: USB-A-H
X7: DC-2.1MM-5MM; DC-21MM
X8: PN61729-S

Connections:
3.3V: 1.2, C43.1, IC14.24 (VDD_1), IC14.36 (VDD_2), IC14.48 (VDD_3), JP1.2, PS1.2 (VOUT), R30.2, R31.2
3.3V_VDDA: C44.1, IC14.9 (VDDA), R30.1
5V: C3.1, C5.1, C7.1, C11.+, C23.1, C25.1, C26.1, C41.1, C45.1, FB.1, IC1.2 (VIN), IC3.1 (DVDD), IC3.5 (AVDD), IC5.8 (VDD), IC8.8 (VDD), JP1.1, PS1.3 (VIN)
12VIN: C30.1, C33.1, C35.1, C40.+, IC13.G3 (RUN), IC13.G4 (VIN_1), IC13.G5 (VIN_2), IC13.H4 (VIN_3), IC13.H5 (VIN_4), L2.2, L3.2, U2.4 (EN), U2.5 (IN)
+13.4V: C17.2, C21.1, C29.+, C38.2, IC2.7 (V+), IC4.4 (V+), IC6.4 (V+), IC9.4 (VDD), IC10.4 (V+), IC12.5 (VOUT), IC16.4 (V+), IC17.4 (V+), IC18.4 (V+), R29.1
+15V: C31.2, C32.1, C36.+, IC12.1 (VIN), IC12.3 (EN), L1.2
-13.4V: C16.1, C20.1, C39.2, C42.-, IC2.4 (V-), IC2.9 (EP), IC4.7 (V-), IC6.11 (V-), IC9.7 (VSS), IC10.11 (V-), IC11.5 (VOUT), IC16.7 (V-), IC17.7 (V-), IC18.7 (V-), R25.1
-15V: C27.1, C34.1, C37.2, IC11.2 (VIN), IC11.3 (EN), IC13.A4 (VOUT-_1), IC13.A5 (VOUT-_2), IC13.B4 (VOUT-_3), IC13.B5 (VOUT-_4), R23.2
CC1: J2.A5 (CC1), R21.1
CC2: J2.B5 (CC2), R20.1
CE: CE.1, IC10.3 (+IN_A), R10.2, R11.2, R12.2, R13.2, X6.GND
CELL_ON: IC14.26 (PB13), R38.1
CS1: IC3.14 (!CS), IC14.10 (PA0)
CS2: IC5.7 (!CS), IC8.7 (!CS), IC14.11 (PA1)
D+: IC14.33 (PA12), J2.A6 (DP1), J2.B6 (DP2), X8.3
D-: IC14.32 (PA11), J2.A7 (DN1), J2.B7 (DN2), X8.2
DAC_OUT: IC6.5 (+IN_B), IC16.1 (COM)
EXT_ADC1: IC17.2 (NC), R2.1
EXT_ADC2: IC18.2 (NC), R3.1
EXT_DAC: C9.1, IC3.11 (VOUT), IC16.2 (NC)
GND: 0.1, C1.2, C2.2, C3.2, C4.2, C5.2, C6.2, C7.2, C8.2, C11.-, C12.2, C13.2, C14.2, C15.2, C16.2, C17.1, C20.2, C21.2, C23.2, C24.2, C25.2, C26.2, C27.2, C28.2, C29.-, C30.2, C31.1, C32.2, C33.2, C34.2, C35.2, C36.-, C37.1, C38.1, C39.1, C40.-, C41.2, C42.+, C43.2, C44.2, C45.2, C46.1, C47.1, C48.2, GND.1, IC1.4 (GND), IC3.4 (DGND), IC3.13 (AGND), IC4.3 (GND), IC5.4 (VSS), IC8.4 (VSS), IC9.3 (GND), IC11.1 (GND), IC12.2 (GND), IC13.A1 (VOUT+_1), IC13.A2 (VOUT+_2), IC13.B1 (VOUT+_3), IC13.B2 (VOUT+_4), IC13.B3 (GND_1), IC13.C1 (GND_2), IC13.C2 (GND_3), IC13.C3 (GND_4), IC13.C4 (GND_5), IC13.C5 (GND_6), IC13.D1 (GND_7), IC13.D2 (GND_8), IC13.D3 (GND_9), IC13.D4 (GND_10), IC13.D5 (GND_11), IC13.E2 (GND_12), IC13.E3 (GND_13), IC13.E4 (GND_14), IC13.E5 (GND_15), IC13.F2 (GND_16), IC13.F3 (GND_17), IC13.F4 (GND_18), IC13.F5 (GND_19), IC13.H1 (GND_21), IC13.H2 (GND_22), IC13.H3 (GND_23), IC14.8 (VSSA), IC14.23 (VSS_1), IC14.35 (VSS_2), IC14.47 (VSS_3), IC16.3 (GND), IC17.3 (GND), IC18.3 (GND), J2.A1 (GND), J2.A12 (GND), J2.B1 (GND), J2.B12 (GND), J2.P1 (SHELL), J2.P2 (SHELL), J2.P3 (SHELL), J2.P4 (SHELL), JP1.3, K1.3 (COIL_2), K2.3 (COIL_2), K2.4 (NO), K3.3 (COIL_2), K3.4 (NO), K4.3 (COIL_2), K4.4 (NO), K5.3 (COIL_2), K5.4 (NO), PS1.1 (VSS), R1.1, R14.2, R18.1, R20.2, R21.2, R22.1, R24.2, R27.1, R28.2, U2.2 (GND), X7.1, X7.3 (2), X8.4, X8.S1, X8.S2
I_E_SWITCH: IC14.19 (PB1), IC16.6 (IN), IC17.6 (IN), IC18.6 (IN)
I_MEAS: C22.1, IC4.8 (NO), IC9.8 (SB), IC10.14 (OUT_D), IC18.1 (COM), R19.2
MODE_SW: IC4.6 (IN), IC9.6 (IN), IC14.18 (PB0)
unnamed: C6.1, IC5.2 (VIN+), R2.2
unnamed: C8.1, IC8.2 (VIN+), R3.2
unnamed: R34.2, T1.B
unnamed: C46.2, IC14.3 (PC14-OSC32_IN), Q1.3 (2)
unnamed: C14.1, IC3.3 (XIN), X1.2
unnamed: C13.1, IC3.2 (XOUT), X1.1
unnamed: C9.2, IC3.10 (C2)
unnamed: C10.2, IC3.9 (C1)
unnamed: IC4.1 (COM), IC9.1 (D), R4.1
unnamed: C18.2, IC6.6 (-IN_B), R4.2
unnamed: IC2.3 (VIN), IC6.7 (OUT_B)
unnamed: C18.1, IC2.6 (VO), K1.1 (NO_), R5.1
unnamed: C15.1, R5.2
unnamed: IC4.5 (N.C.), IC9.5 (NC)
unnamed: IC6.3 (+IN_A), R6.1, R7.1
unnamed: C19.2, IC6.2 (-IN_A), R8.1, R9.2
unnamed: K2.1 (NO_), R10.1
unnamed: IC10.1 (OUT_A), R15.1, R16.2
unnamed: K3.1 (NO_), R11.1
unnamed: IC10.2 (-IN_A), R14.1, R15.2
unnamed: K4.1 (NO_), R12.1
unnamed: C12.1, D6.C, L1.1, R26.2
unnamed: K5.1 (NO_), R13.1
unnamed: IC10.12 (+IN_D), R16.1, R17.1
unnamed: C28.1, D7.C, D8.C, L3.1
unnamed: C22.2, IC10.13 (-IN_D), R18.2, R19.1
unnamed: IC11.4 (ADJ), R24.1, R25.2
unnamed: D8.A, X7.2 (3)
unnamed: IC12.4 (SENSE/ADJ), R28.1, R29.2
unnamed: C47.2, IC14.4 (PC15-OSC32_OUT), Q1.1
unnamed: 0.2, 1.1, IC14.44 (BOOT0)
unnamed: R35.2, T2.B
unnamed: IC13.G1 (RT), R22.2
unnamed: IC13.A3 (FB), R23.1
unnamed: R36.2, T3.B
unnamed: R37.2, T4.B
unnamed: R38.2, T5.B
unnamed: D6.A, L2.1, U2.1 (SW)
unnamed: R26.1, R27.2, U2.3 (FB)
RANGE1: IC14.20 (PB2), R34.1
RANGE2: IC14.21 (PB10), R35.1
RANGE3: IC14.22 (PB11), R36.1
RANGE4: IC14.25 (PB12), R37.1
RE: IC6.10 (+IN_C), RE.1, X6.D-
RELAY1: K2.2 (COIL_1), T1.C
RELAY2: K3.2 (COIL_1), T2.C
RELAY3: K4.2 (COIL_1), T3.C
RELAY4: K5.2 (COIL_1), T4.C
RELAY_CELL: K1.2 (COIL_1), T5.C
RE_BUFF: IC6.8 (OUT_C), IC6.9 (-IN_C), R8.2
RST: C48.1, IC14.7 (NRST), JP1.6, R31.1
SCK: IC3.16 (SCLK), IC5.5 (SCK), IC8.5 (SCK), IC14.15 (PA5)
SDIO: IC5.6 (SDO/!RDY), IC14.12 (PA2)
SDIO2: IC8.6 (SDO/!RDY), IC14.13 (PA3)
SDIO_DAC: IC3.15 (SDIO), IC14.14 (PA4), IC16.8 (NO)
SE: IC6.12 (+IN_D), SE.1, X6.D+
SE_BUFF: IC6.13 (-IN_D), IC6.14 (OUT_D), R7.2
STM_ADC1: IC17.8 (NO), R32.1
STM_ADC1_INP: C1.1, IC14.16 (PA6), R32.2
STM_ADC2: IC18.8 (NO), R33.1
STM_ADC2_INP: C2.1, IC14.17 (PA7), R33.2
SWCLK: IC14.37 (PA14), JP1.5
SWDIO: IC14.34 (PA13), JP1.4
VBAT: IC14.1 (VBAT)
VBUS: C24.1, D7.A, FB.2, J2.A4 (VBUS), J2.A9 (VBUS), J2.B4 (VBUS), J2.B9 (VBUS), T1.E, T2.E, T3.E, T4.E, T5.E, X8.1
VREF: C4.1, C10.1, IC1.6 (VOUT), IC3.12 (VREF), IC5.1 (VREF), IC5.3 (VIN-), IC8.1 (VREF), IC8.3 (VIN-), R1.2, R6.2, R17.2
V_MEAS: C19.1, IC4.2 (NC), IC6.1 (OUT_A), IC9.2 (SA), IC17.1 (COM), R9.1
WE: K1.4 (NO), WE.1, X6.VBUS

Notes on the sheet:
SDIO_DAC = DAC_OUT_1

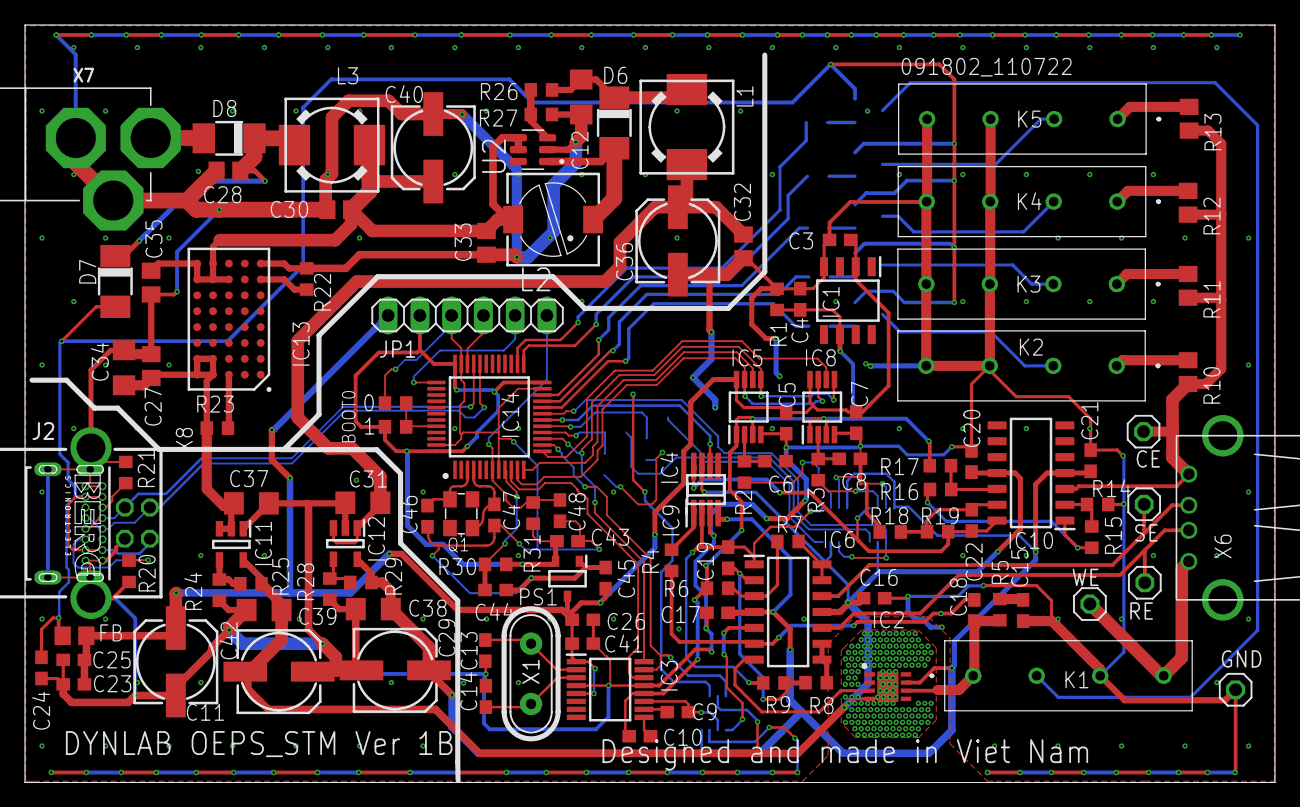
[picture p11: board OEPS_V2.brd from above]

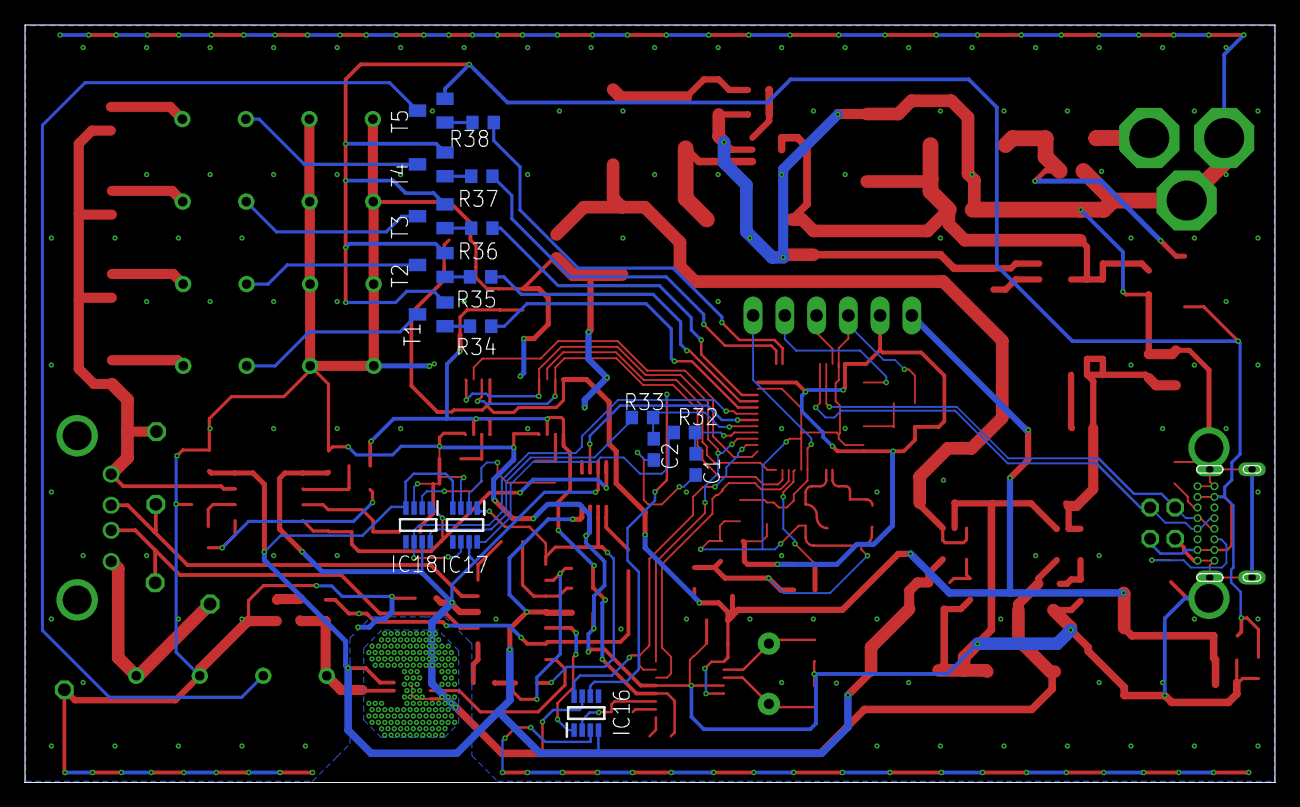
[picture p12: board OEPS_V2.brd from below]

Board: 2 copper layers, 100.0 x 60.6 mm, 135 parts (17 on the bottom side), 91 nets.

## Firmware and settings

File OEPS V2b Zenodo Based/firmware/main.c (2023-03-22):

/*
 * USB Potentiostat/galvanostat firmware
 *
 * This code makes use of Signal 11's M-Stack USB stack to implement 
 * communication through raw USB bulk transfers. Commands are received
 * as ASCII strings on EP1 OUT. They are then interpreted and executed;
 * they either change the state of output pins, or cause data to be read
 * from / written to the MCP3550 (ADC) or DAC1220 (DAC) using a software
 * SPI implementation. The resulting data, or an "OK" message, is sent as
 * a reply on EP1 IN. The USB service is interrupt-driven.
 *
 * Thomas Dobbelaere
 * CoCooN research group
 * 2016-06-07
 */

#include "usb.h"
#include <xc.h>
#include <string.h>
#include "usb_config.h"
#include "usb_ch9.h"
#include "spi_software.h"
#include "Flash.h"
#include "HEFlash.h"

// PIC16F1459 configuration bit settings:
// CONFIG1
#pragma config FOSC = INTOSC    // Oscillator Selection Bits (INTOSC oscillator: I/O function on CLKIN pin)
#pragma config WDTE = OFF       // Watchdog Timer Enable (WDT disabled)
#pragma config PWRTE = OFF      // Power-up Timer Enable (PWRT disabled)
#pragma config MCLRE = OFF      // MCLR Pin Function Select (MCLR/VPP pin function is digital input)
#pragma config CP = OFF         // Flash Program Memory Code Protection (Program memory code protection is disabled)
#pragma config BOREN = ON       // Brown-out Reset Enable (Brown-out Reset enabled)
#pragma config CLKOUTEN = OFF   // Clock Out Enable (CLKOUT function is disabled. I/O or oscillator function on the CLKOUT pin)
#pragma config IESO = OFF       // Internal/External Switchover Mode (Internal/External Switchover Mode is disabled)
#pragma config FCMEN = OFF      // Fail-Safe Clock Monitor Enable (Fail-Safe Clock Monitor is disabled)

// CONFIG2
#pragma config WRT = OFF        // Flash Memory Self-Write Protection (Write protection off)
#pragma config CPUDIV = NOCLKDIV// CPU System Clock Selection Bit (NO CPU system divide)
#pragma config USBLSCLK = 48MHz // USB Low Speed Clock Selection bit (System clock expects 48 MHz, FS/LS USB CLKENs divide-by is set to 8.)
#pragma config PLLMULT = 3x     // PLL Multipler Selection Bit (3x Output Frequency Selected)
#pragma config PLLEN = ENABLED  // PLL Enable Bit (3x or 4x PLL Enabled)
#pragma config STVREN = ON      // Stack Overflow/Underflow Reset Enable (Stack Overflow or Underflow will cause a Reset)
#pragma config BORV = LO        // Brown-out Reset Voltage Selection (Brown-out Reset Voltage (Vbor), low trip point selected.)
#pragma config LPBOR = OFF      // Low-Power Brown Out Reset (Low-Power BOR is disabled)
#pragma config LVP = OFF        // Low-Voltage Programming Enable (High-voltage on MCLR/VPP must be used for programming)

#define _XTAL_FREQ 48000000     // 48 MHz CPU clock frequency

#define MODE_SW_PIN LATAbits.LATA5
#define MODE_SW_TRIS TRISAbits.TRISA5
#define CELL_ON_PIN LATAbits.LATA4
#define CELL_ON_TRIS TRISAbits.TRISA4
#define CELL_ON  1
#define CELL_OFF 0
#define POTENTIOSTATIC  0
#define GALVANOSTATIC  1
#define INPUT  1
#define OUTPUT 0
#define RANGE1_PIN LATCbits.LATC4
#define RANGE1_TRIS TRISCbits.TRISC4
#define RANGE2_PIN LATCbits.LATC5
#define RANGE2_TRIS TRISCbits.TRISC5
#define RANGE3_PIN LATCbits.LATC6
#define RANGE3_TRIS TRISCbits.TRISC6

static const uint8_t* received_data;
static uint8_t received_data_length;
static uint8_t* transmit_data;
static uint8_t transmit_data_length;
static uint8_t heflashbuffer[FLASH_ROWSIZE];

void InitializeIO()
{
	OSCCONbits.IRCF = 0b1111; // 0b1111 = 16MHz HFINTOSC postscaler
	ANSELA = 0x00; // digital I/O on PORTA
	ANSELB = 0x00; // digital I/O on PORTB
	ANSELC = 0x00; // digital I/O on PORTC
	APFCON = 0x00; // no funny alternate pins
	MODE_SW_TRIS = OUTPUT;
	MODE_SW_PIN = POTENTIOSTATIC; // initialize mode to potentiostatic
	CELL_ON_TRIS = OUTPUT;
	CELL_ON_PIN = CELL_OFF; // initialize cell to off position
	RANGE1_TRIS = OUTPUT;
	RANGE2_TRIS = OUTPUT;
	RANGE3_TRIS = OUTPUT;
	RANGE1_PIN = 1; // initialize range to range 1
	RANGE2_PIN = 0;
	RANGE3_PIN = 0;
	InitializeSPI();
	__delay_ms(25); // power-up delay - necessary for DAC1220
	DAC1220_Reset();
	__delay_ms(25);
	DAC1220_Init();
	HEFLASH_readBlock(heflashbuffer, 2, FLASH_ROWSIZE); // get dac calibration
	DAC1220_Write3Bytes(8, heflashbuffer[0], heflashbuffer[1], heflashbuffer[2]); // apply dac calibration
	DAC1220_Write3Bytes(12, heflashbuffer[3], heflashbuffer[4], heflashbuffer[5]); 
}

void command_unknown()
{
	const uint8_t* reply = "?";
    strcpy(transmit_data, reply);
    transmit_data_length = strlen(reply);
}

void send_OK()
{
	const uint8_t* reply = "OK";
    strcpy(transmit_data, reply);
    transmit_data_length = strlen(reply);
}

void command_cell_on()
{
	CELL_ON_PIN = CELL_ON;
	send_OK();
}

void command_cell_off()
{
	CELL_ON_PIN = CELL_OFF;
	send_OK();
}

void command_mode_potentiostatic()
{
	MODE_SW_PIN = POTENTIOSTATIC;
	send_OK();
}

void command_mode_galvanostatic()
{
	MODE_SW_PIN = GALVANOSTATIC;
	send_OK();
}

void command_range1()
{
    RANGE1_PIN = 1;
    __delay_ms(10); // make the new relay setting before breaking the old one
    RANGE2_PIN = 0;
    RANGE3_PIN = 0;
	send_OK();
}

void command_range2()
{
    RANGE2_PIN = 1;
    __delay_ms(10); // make the new relay setting before breaking the old one
    RANGE1_PIN = 0;
    RANGE3_PIN = 0;
	send_OK();
}

void command_range3()
{
    RANGE3_PIN = 1;
    __delay_ms(10); // make the new relay setting before breaking the old one
    RANGE1_PIN = 0;
    RANGE2_PIN = 0;
	send_OK();
}

void command_set_dac(const uint8_t* dac_data)
{
	DAC1220_Write3Bytes(0, dac_data[0], dac_data[1], dac_data[2]);
	send_OK();
}

void command_calibrate_dac()
{
	DAC1220_SelfCal();
	__delay_ms(500); // wait until calibration is finished
	uint8_t data[6];
	DAC1220_Read3Bytes(8, data, data+1, data+2); // get calibration data
	DAC1220_Read3Bytes(12, data+3, data+4, data+5);
	HEFLASH_writeBlock(2, data, 6); // save calibration data to HEFLASH
	send_OK();
}

void command_read_adc()
{
	uint8_t adc_data[6];
	if(MCP3550_Read(adc_data))
	{
		transmit_data_length=6;
		memcpy(transmit_data, adc_data, transmit_data_length);
	}
	else
	{
		const uint8_t* reply = "WAIT";
		strcpy(transmit_data, reply);
		transmit_data_length = strlen(reply);
	}
}

void command_read_offset()
{
	HEFLASH_readBlock(heflashbuffer, 1, FLASH_ROWSIZE);
	transmit_data_length=6;
	memcpy(transmit_data, heflashbuffer, transmit_data_length);
}

void command_save_offset(const uint8_t* offset_data)
{
	HEFLASH_writeBlock(1, offset_data, 6);
	send_OK();
}

void command_read_shuntcalibration()
{
	HEFLASH_readBlock(heflashbuffer, 3, FLASH_ROWSIZE);
	transmit_data_length=6;
	memcpy(transmit_data, heflashbuffer, transmit_data_length);
}

void command_save_shuntcalibration(const uint8_t* shuntcalibration_data)
{
	HEFLASH_writeBlock(3, shuntcalibration_data, 6);
	send_OK();
}

void command_read_dac_cal()
{
	HEFLASH_readBlock(heflashbuffer, 2, FLASH_ROWSIZE);
	transmit_data_length=6;
	memcpy(transmit_data, heflashbuffer, transmit_data_length);
}

void command_set_dac_cal(const uint8_t* dac_cal_data)
{
	HEFLASH_writeBlock(2, dac_cal_data, 6);
	DAC1220_Write3Bytes(8, dac_cal_data[0], dac_cal_data[1], dac_cal_data[2]);
	DAC1220_Write3Bytes(12, dac_cal_data[3], dac_cal_data[4], dac_cal_data[5]);
	send_OK();
}

void interpret_command() {
    if (received_data_length == 7 && strncmp(received_data,"CELL ON",7) == 0)
        command_cell_on();
    else if (received_data_length == 8 && strncmp(received_data,"CELL OFF",8) == 0)
        command_cell_off();
    else if (received_data_length == 14 && strncmp(received_data,"POTENTIOSTATIC",14) == 0)
        command_mode_potentiostatic();
    else if (received_data_length == 13 && strncmp(received_data,"GALVANOSTATIC",13) == 0)
        command_mode_galvanostatic();
    else if (received_data_length == 7 && strncmp(received_data,"RANGE 1",7) == 0)
        command_range1();
    else if (received_data_length == 7 && strncmp(received_data,"RANGE 2",7) == 0)
        command_range2();
    else if (received_data_length == 7 && strncmp(received_data,"RANGE 3",7) == 0)
        command_range3();
    else if (received_data_length == 10 && strncmp(received_data,"DACSET ",7) == 0)
	command_set_dac(received_data+7);
    else if (received_data_length == 6 && strncmp(received_data,"DACCAL",6) == 0)
	command_calibrate_dac();
    else if (received_data_length == 7 && strncmp(received_data,"ADCREAD",7) == 0)
	command_read_adc();
    else if (received_data_length == 10 && strncmp(received_data,"OFFSETREAD",10) == 0)
	command_read_offset();
    else if (received_data_length == 17 && strncmp(received_data,"OFFSETSAVE ",11) == 0)
	command_save_offset(received_data+11);
    else if (received_data_length == 9 && strncmp(received_data,"DACCALGET",9) == 0)
	command_read_dac_cal();
    else if (received_data_length == 16 && strncmp(received_data,"DACCALSET ",10) == 0)
	command_set_dac_cal(received_data+10);
    else if (received_data_length == 12 && strncmp(received_data,"SHUNTCALREAD",12) == 0)
	command_read_shuntcalibration();
    else if (received_data_length == 19 && strncmp(received_data,"SHUNTCALSAVE ",13) == 0)
	command_save_shuntcalibration(received_data+13);
    else
        command_unknown();
}

int main(void)
{
	InitializeIO();

	// Enable Active clock-tuning from the USB
	ACTCONbits.ACTSRC = 1; // 1=USB
	ACTCONbits.ACTEN = 1;

	// Configure interrupts
	INTCONbits.PEIE = 1;
	INTCONbits.GIE = 1;

	// Initialize USB
	usb_init();

	while (1)
	{
		if (usb_is_configured() && usb_out_endpoint_has_data(1)) // wait for data received from host
		{
			if (!usb_in_endpoint_halted(1))
			{
				while (usb_in_endpoint_busy(1)) // wait for EP1 IN to become free
					;
				received_data_length = usb_get_out_buffer(1, &received_data); // get memory location and length of received data
				transmit_data = usb_get_in_buffer(1); // get memory location of data to transmit
				interpret_command(); // this reads received_data and sets transmit_data and transmit_data_length
				usb_send_in_buffer(1, transmit_data_length); // send the data back
			}
			usb_arm_out_endpoint(1);
		}
	}

	return 0;
}

void interrupt isr()
{
	usb_service();
}

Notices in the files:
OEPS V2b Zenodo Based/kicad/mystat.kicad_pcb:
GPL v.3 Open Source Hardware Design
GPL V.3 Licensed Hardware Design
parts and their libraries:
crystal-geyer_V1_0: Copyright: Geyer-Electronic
